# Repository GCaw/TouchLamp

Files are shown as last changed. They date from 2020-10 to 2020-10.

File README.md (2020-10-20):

# TouchLamp
Schematics, Drawings and code to build my TouchLamp

This was an entry for the [2020 Hackaday Circuit Sculpture Contest](https://hackaday.io/contest/174093-2020-circuit-sculpture-challenge). Project Page: [link](https://hackaday.io/project/175482-circuit-sculpture-touch-lamp-with-pcb-shade). 

For more info on the design and build, see my [blog](https://blog.gcawood.com/2020/10/20/circuit-sculpture-touch-lamp-with-pcb-shade/).

A brief demo can be seen [here](https://www.youtube.com/watch?v=Q-MZvJV5pA0&feature=youtu.be).

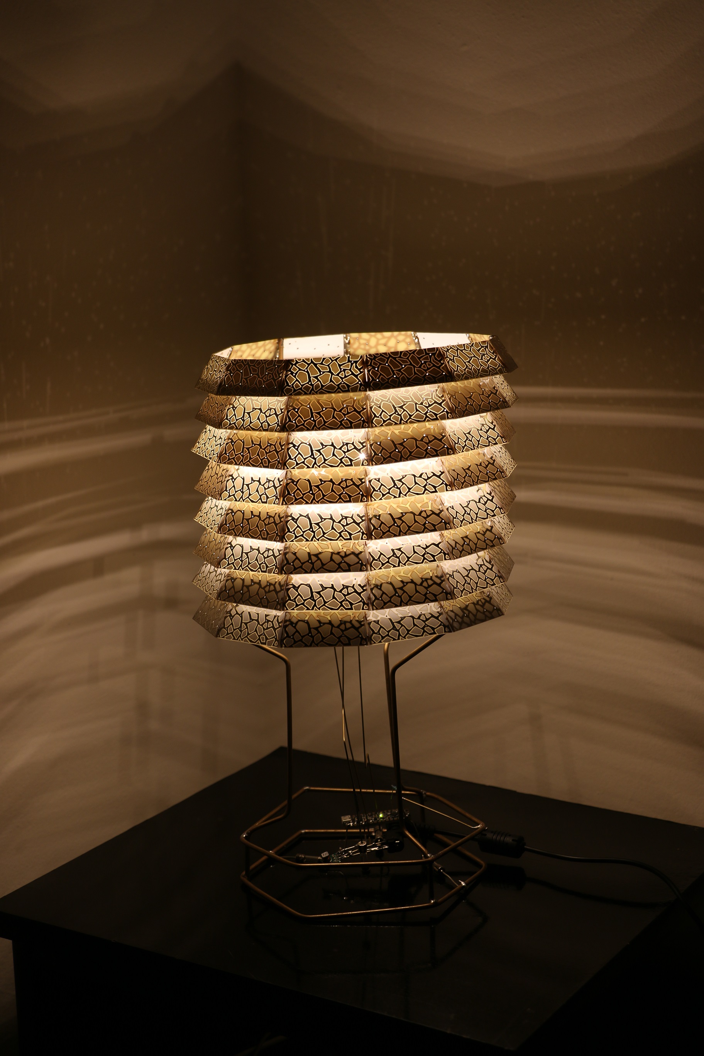
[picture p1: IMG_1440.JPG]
Image of the project


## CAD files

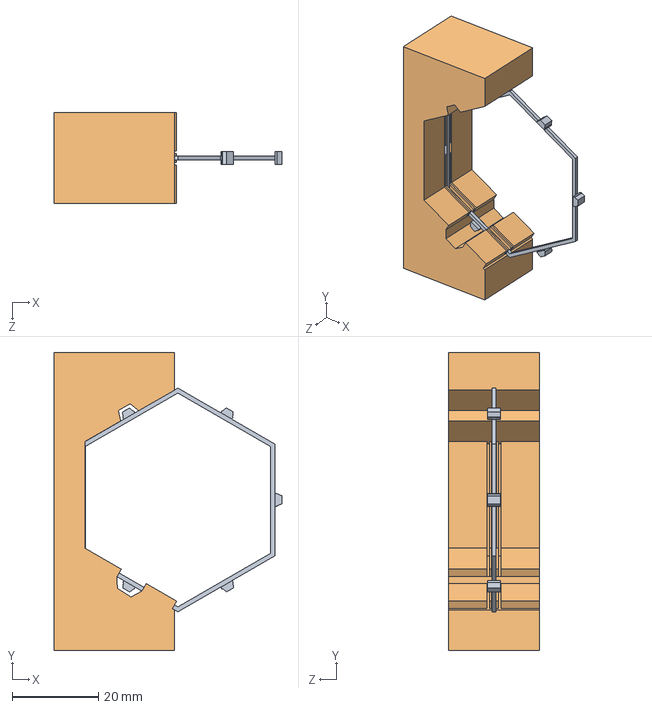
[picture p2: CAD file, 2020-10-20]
Models/RingLightToolAss.SLDASM
52.7 x 69.0 x 21.0 mm
LEDRing
LedRingJig

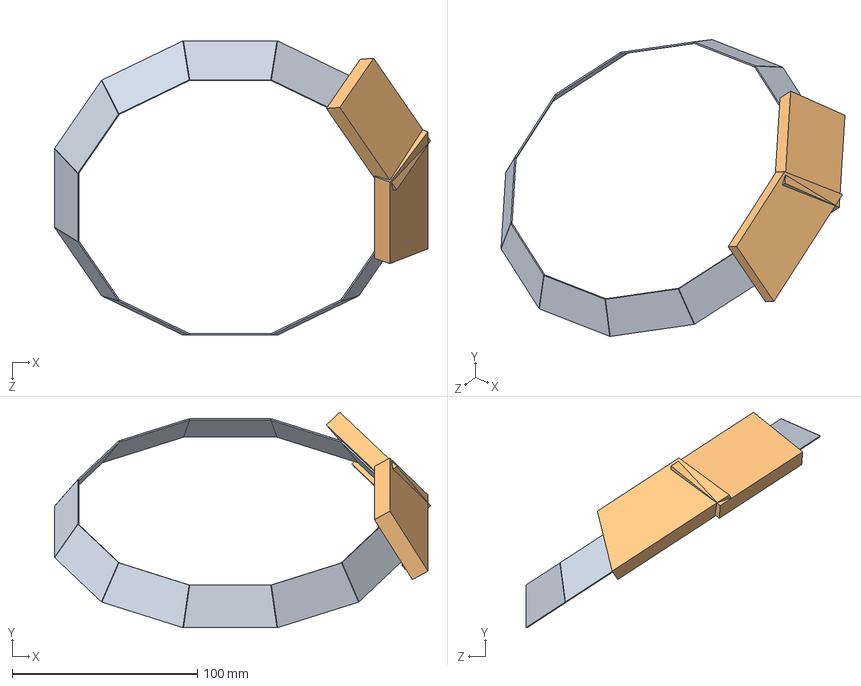
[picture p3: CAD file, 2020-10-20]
Models/Assembled.SLDASM
202.9 x 116.3 x 158.9 mm
Panels x 12
PanelHolder^Assembled

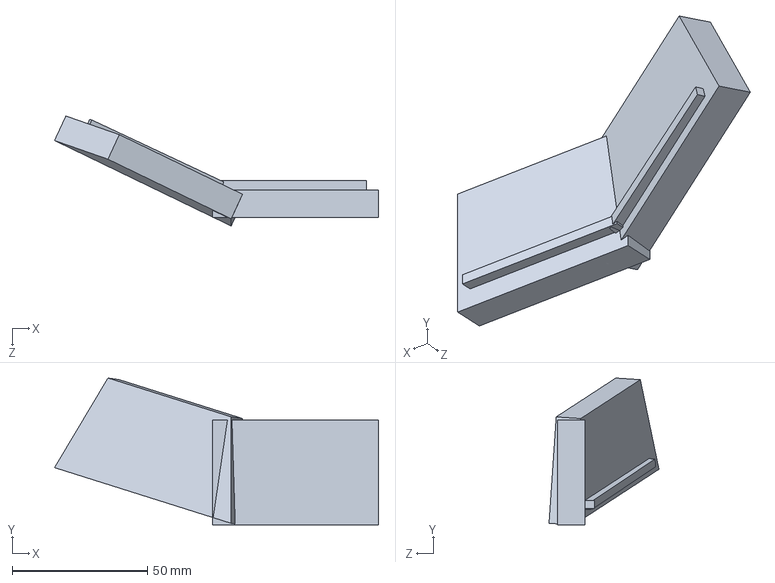
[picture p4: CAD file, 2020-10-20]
Models/PanelHolder.sldprt
119.7 x 54.3 x 40.6 mm

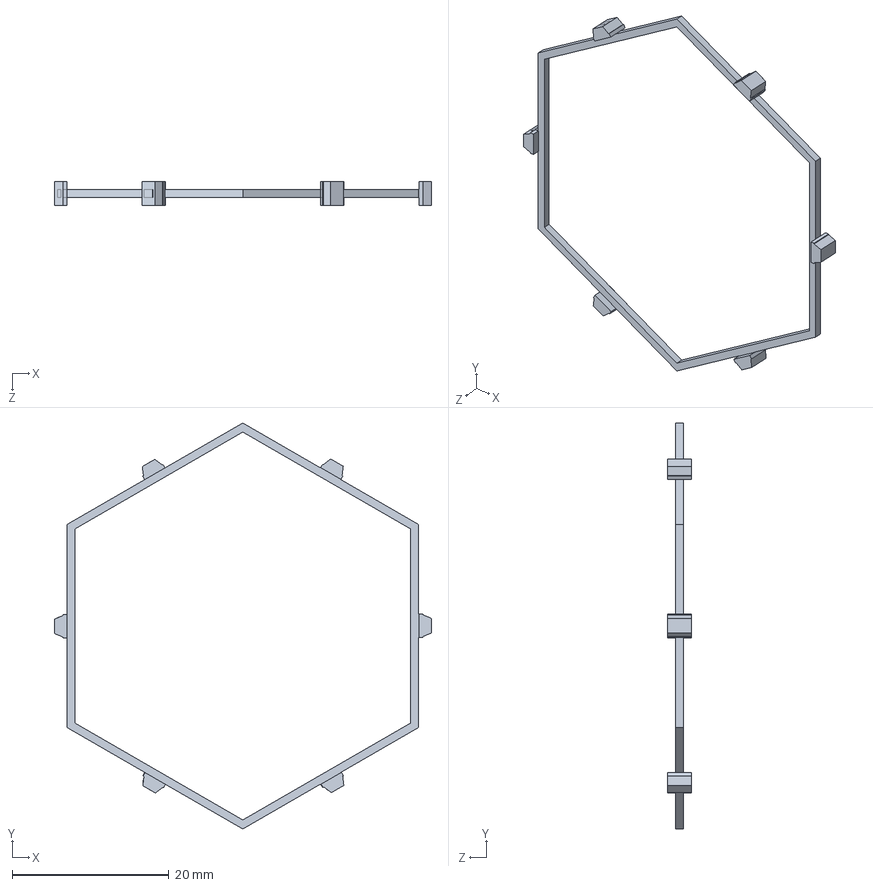
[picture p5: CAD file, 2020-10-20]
Models/LEDRing.SLDPRT
48.1 x 51.8 x 3.00 mm

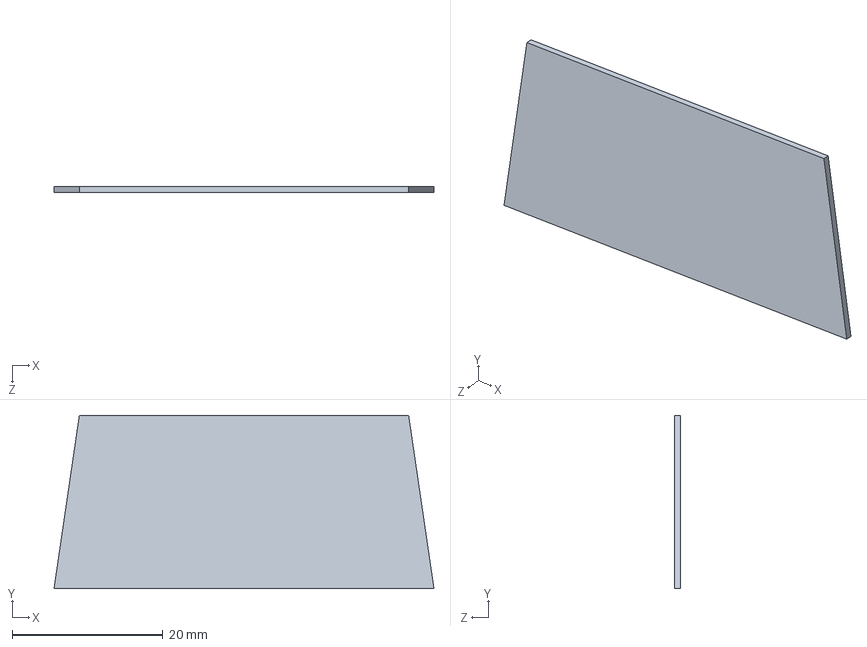
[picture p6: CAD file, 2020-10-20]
Models/Panels.SLDPRT
50.5 x 23.0 x 0.8 mm

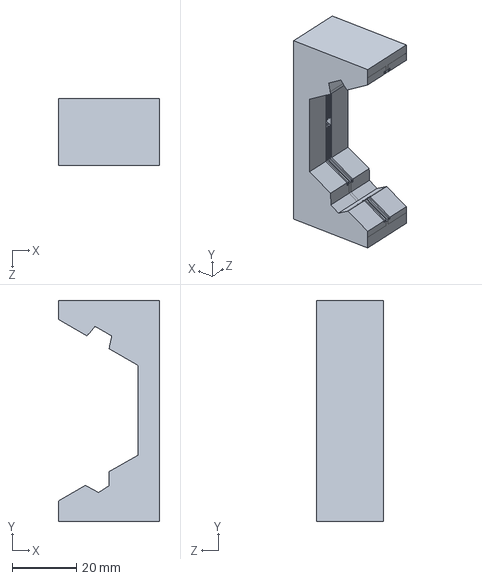
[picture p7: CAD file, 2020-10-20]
Models/LedRingJig.sldprt
31.5 x 69.0 x 21.0 mm

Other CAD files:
Models/DrawingCheck.SLDPRT
Models/panelizing.SLDPRT

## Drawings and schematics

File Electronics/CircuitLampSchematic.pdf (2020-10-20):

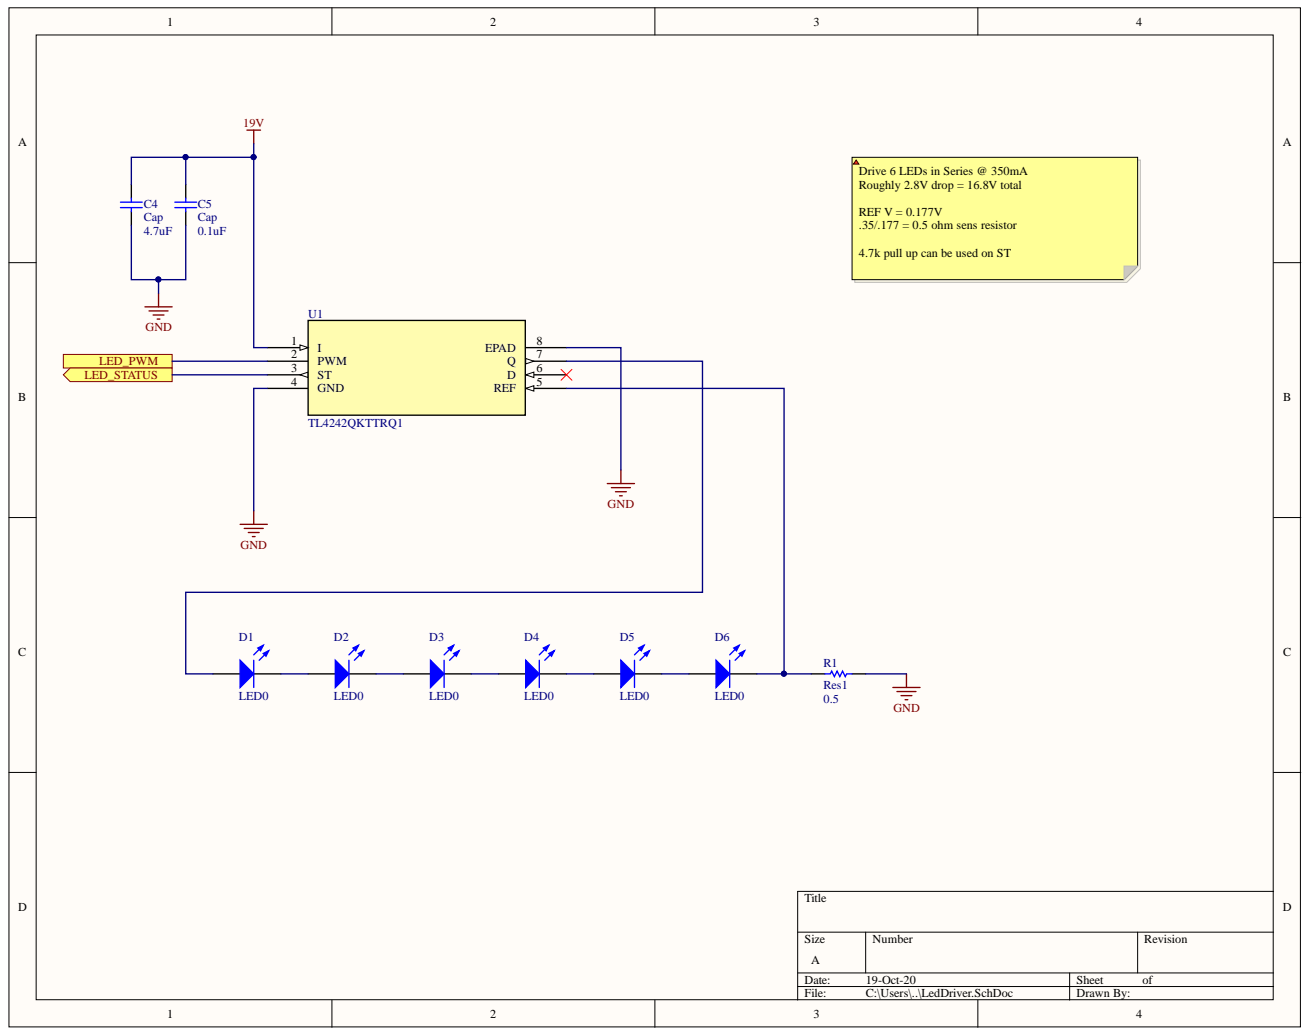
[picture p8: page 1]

Drive 6 LEDs in Series @ 350mA
Roughly 2.8V drop = 16.8V total

4.7k pull up can be used on ST

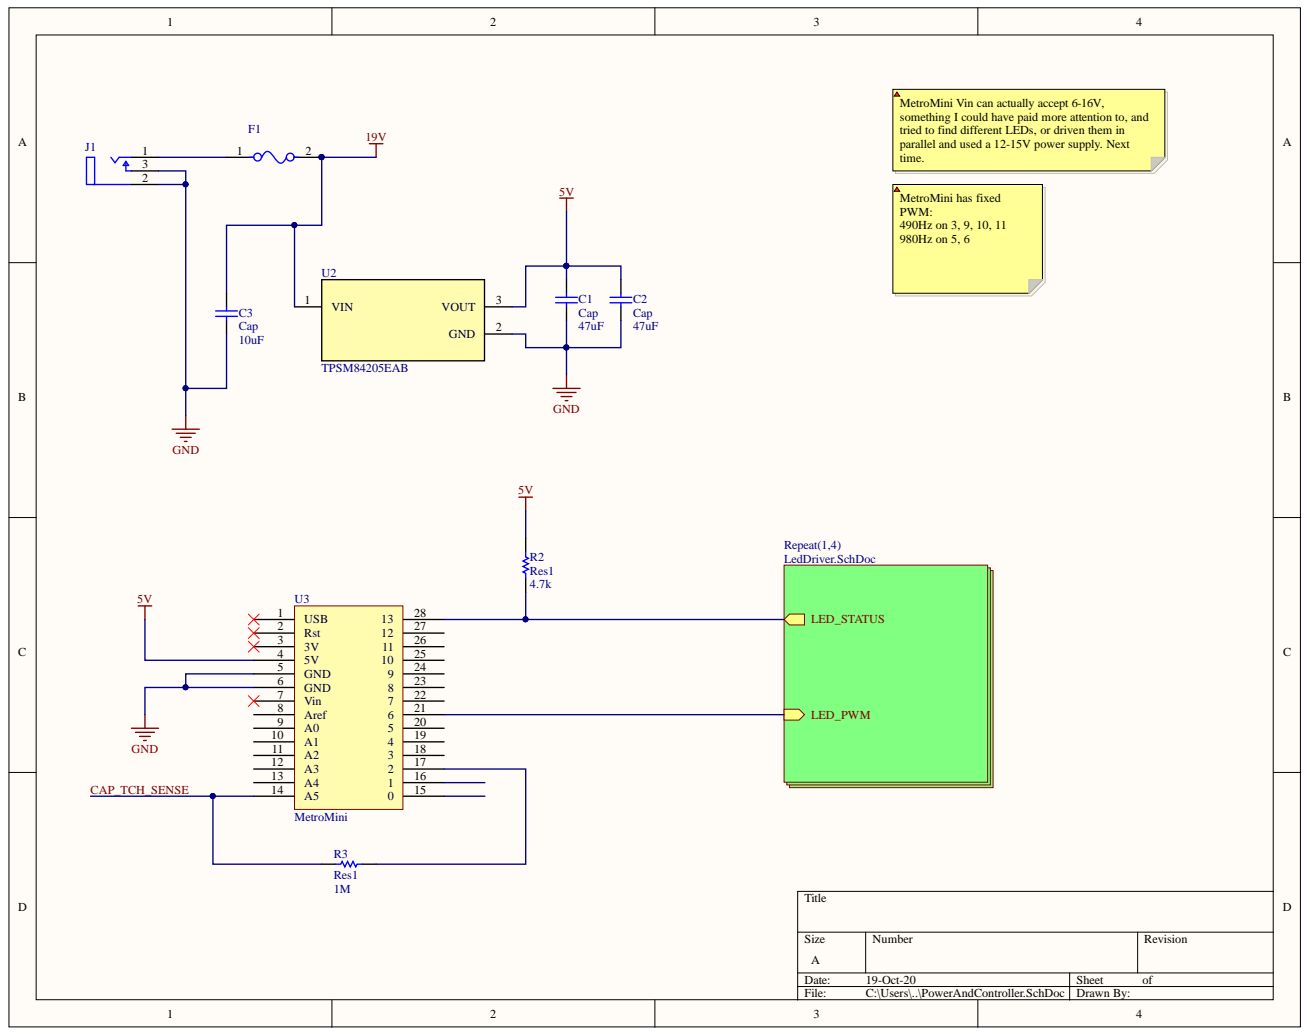
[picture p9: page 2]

MetroMini Vin can actually accept 6-16V,
something I could have paid more attention to, and
tried to find different LEDs, or driven them in
parallel and used a 12-15V power supply. Next
time.

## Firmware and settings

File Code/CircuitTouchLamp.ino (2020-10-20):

/*
board info: https://www.adafruit.com/product/2590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
arduino programming: https://www.arduino.cc/reference/en/
mcu: https://www.microchip.com/wwwproducts/en/atmega328p
*/
 
int ANALOG_MAX = 1023;
int ANLALOG_THRESH = 100;
unsigned long LAST_TOUCH_TOL = 3000000; //us - time between touches

int PIN_TOUCH = A5;       // read voltage to determine if touching or not
int PIN_TOUCH_CHARGE = 2; // pin to toggle charge on RC circuit for touch
int PIN_LED = 13;         // on board diagnostic LED
int PIN_PWM = 6;          // PWM output pin for driving lamp LEDs

unsigned long startTime;
unsigned long endTime;
unsigned long lastTouch = 0;
bool ledToggle = true;
int chargetime = 0;
int counter = 0;
bool light_on = false;
int incrementer = 1;

void setup() {
  analogWrite(PIN_PWM, 0);
  
  Serial.begin(9600);
  analogReference(DEFAULT); // Default for Uno is 5V
  
  pinMode(PIN_TOUCH_CHARGE, OUTPUT);
  digitalWrite(PIN_TOUCH_CHARGE, LOW);
  
  pinMode(PIN_LED, OUTPUT);
  digitalWrite(PIN_LED, LOW);
  
  Calibrate();
}


void loop()
{
    if (BeingTouched())
    {
      if (micros() - lastTouch > LAST_TOUCH_TOL)
      {
        if (counter > 0)
        {
          counter = 0;
          incrementer = 1;
        }
        else
        {
          counter = 7;
        }
      }
      else
      {
        // PWM write value is 0-255.
        // we want to limit max output to the LED drivers, so we max out at 16*5 = 80
        // 80/255 = 31% of max brightness
        counter += incrementer;
        if (counter > 15)
        {
          incrementer = -1;
        }
        if (counter < 1)
        {
          incrementer = 1;
        }
      }
      digitalWrite(PIN_LED, HIGH);
      analogWrite(PIN_PWM, 5*counter);
      lastTouch = micros();
      delay(200); //debounce
      Serial.print("\nCounter: ");
      Serial.print(counter);
    }
    else
    {
      digitalWrite(PIN_LED, LOW);
    }
}

// Determine whether the lamp is being touched or not
bool BeingTouched()
{
  bool touched = false;
  int val = 0;
  startTime = micros(); // overflows after 70min
  digitalWrite(PIN_TOUCH_CHARGE, HIGH);
  while (true)
  {
    val = analogRead(PIN_TOUCH);
    if (val >= ANALOG_MAX - ANLALOG_THRESH)
    {
      touched = false;
      break;
    }
    
    endTime = micros() - startTime;
    if (endTime > chargetime*2)
    {
      Serial.print("\ntime: ");
      Serial.print(endTime);
      Serial.print("\nPushed\n\n");
      touched = true;
      break;
    }
    
  }
  
  digitalWrite(PIN_TOUCH_CHARGE, LOW);
  return touched;
}

// Get a baseline for how long a charge discharge cycle should take.
// Assumes no one is touching it.
bool Calibrate()
{
  int cal_loops = 5;
  for (int i = 0; i < cal_loops; i++)
  {
    startTime = micros(); // overflows after 70min
    int val = 0;
    digitalWrite(PIN_TOUCH_CHARGE, HIGH);
    while (val < ANALOG_MAX - ANLALOG_THRESH)
    {
      val = analogRead(PIN_TOUCH);
    }
    digitalWrite(PIN_TOUCH_CHARGE, LOW);
    while (val > ANLALOG_THRESH)
    {
      val = analogRead(PIN_TOUCH);
    }
    endTime = micros();
    Serial.print("\ncharge: ");
    Serial.print(endTime-startTime);
    chargetime += endTime-startTime;
  }
  
  chargetime = chargetime / cal_loops;
  Serial.print("\ncharge: ");
  Serial.print(chargetime);
}

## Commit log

2020-10-20 Add schematics, code and models
    [Assembled.SLDASM, CircuitLamp.PrjPcb, DrawingCheck.SLDPRT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]
2020-10-20 Add panel holder
    Was only apart of assembly
    [PanelHolder.sldprt]
